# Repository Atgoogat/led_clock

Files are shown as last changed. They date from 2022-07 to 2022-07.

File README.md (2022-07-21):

# LED Clock

This is the pcb and software for a clock showing the time as three vertical led bars. 

The hours are split in two bars, 13h to 23h and 1h-12h, while minutes are split in three groups of 15, 5 and single minutes. Summed up you can read the time.

Time is kept with an RTC-DS3231.
Because the outputs of the arduino uno are not sufficient, shift registers are used to output the time.

Result:
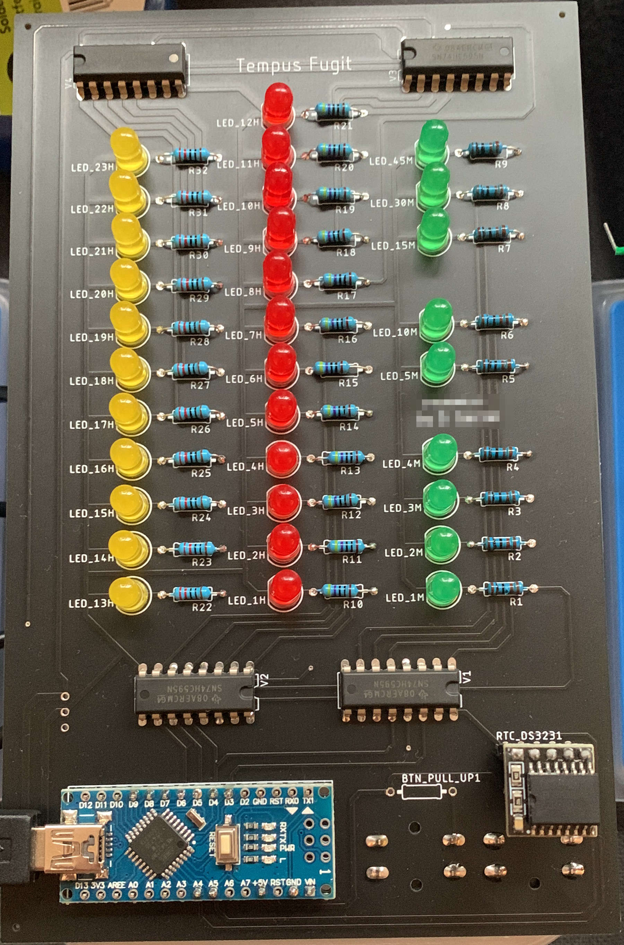
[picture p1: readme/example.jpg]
Result


## Questions

Please contact me via github if you have any questions or want to rebuild this clock 😉.

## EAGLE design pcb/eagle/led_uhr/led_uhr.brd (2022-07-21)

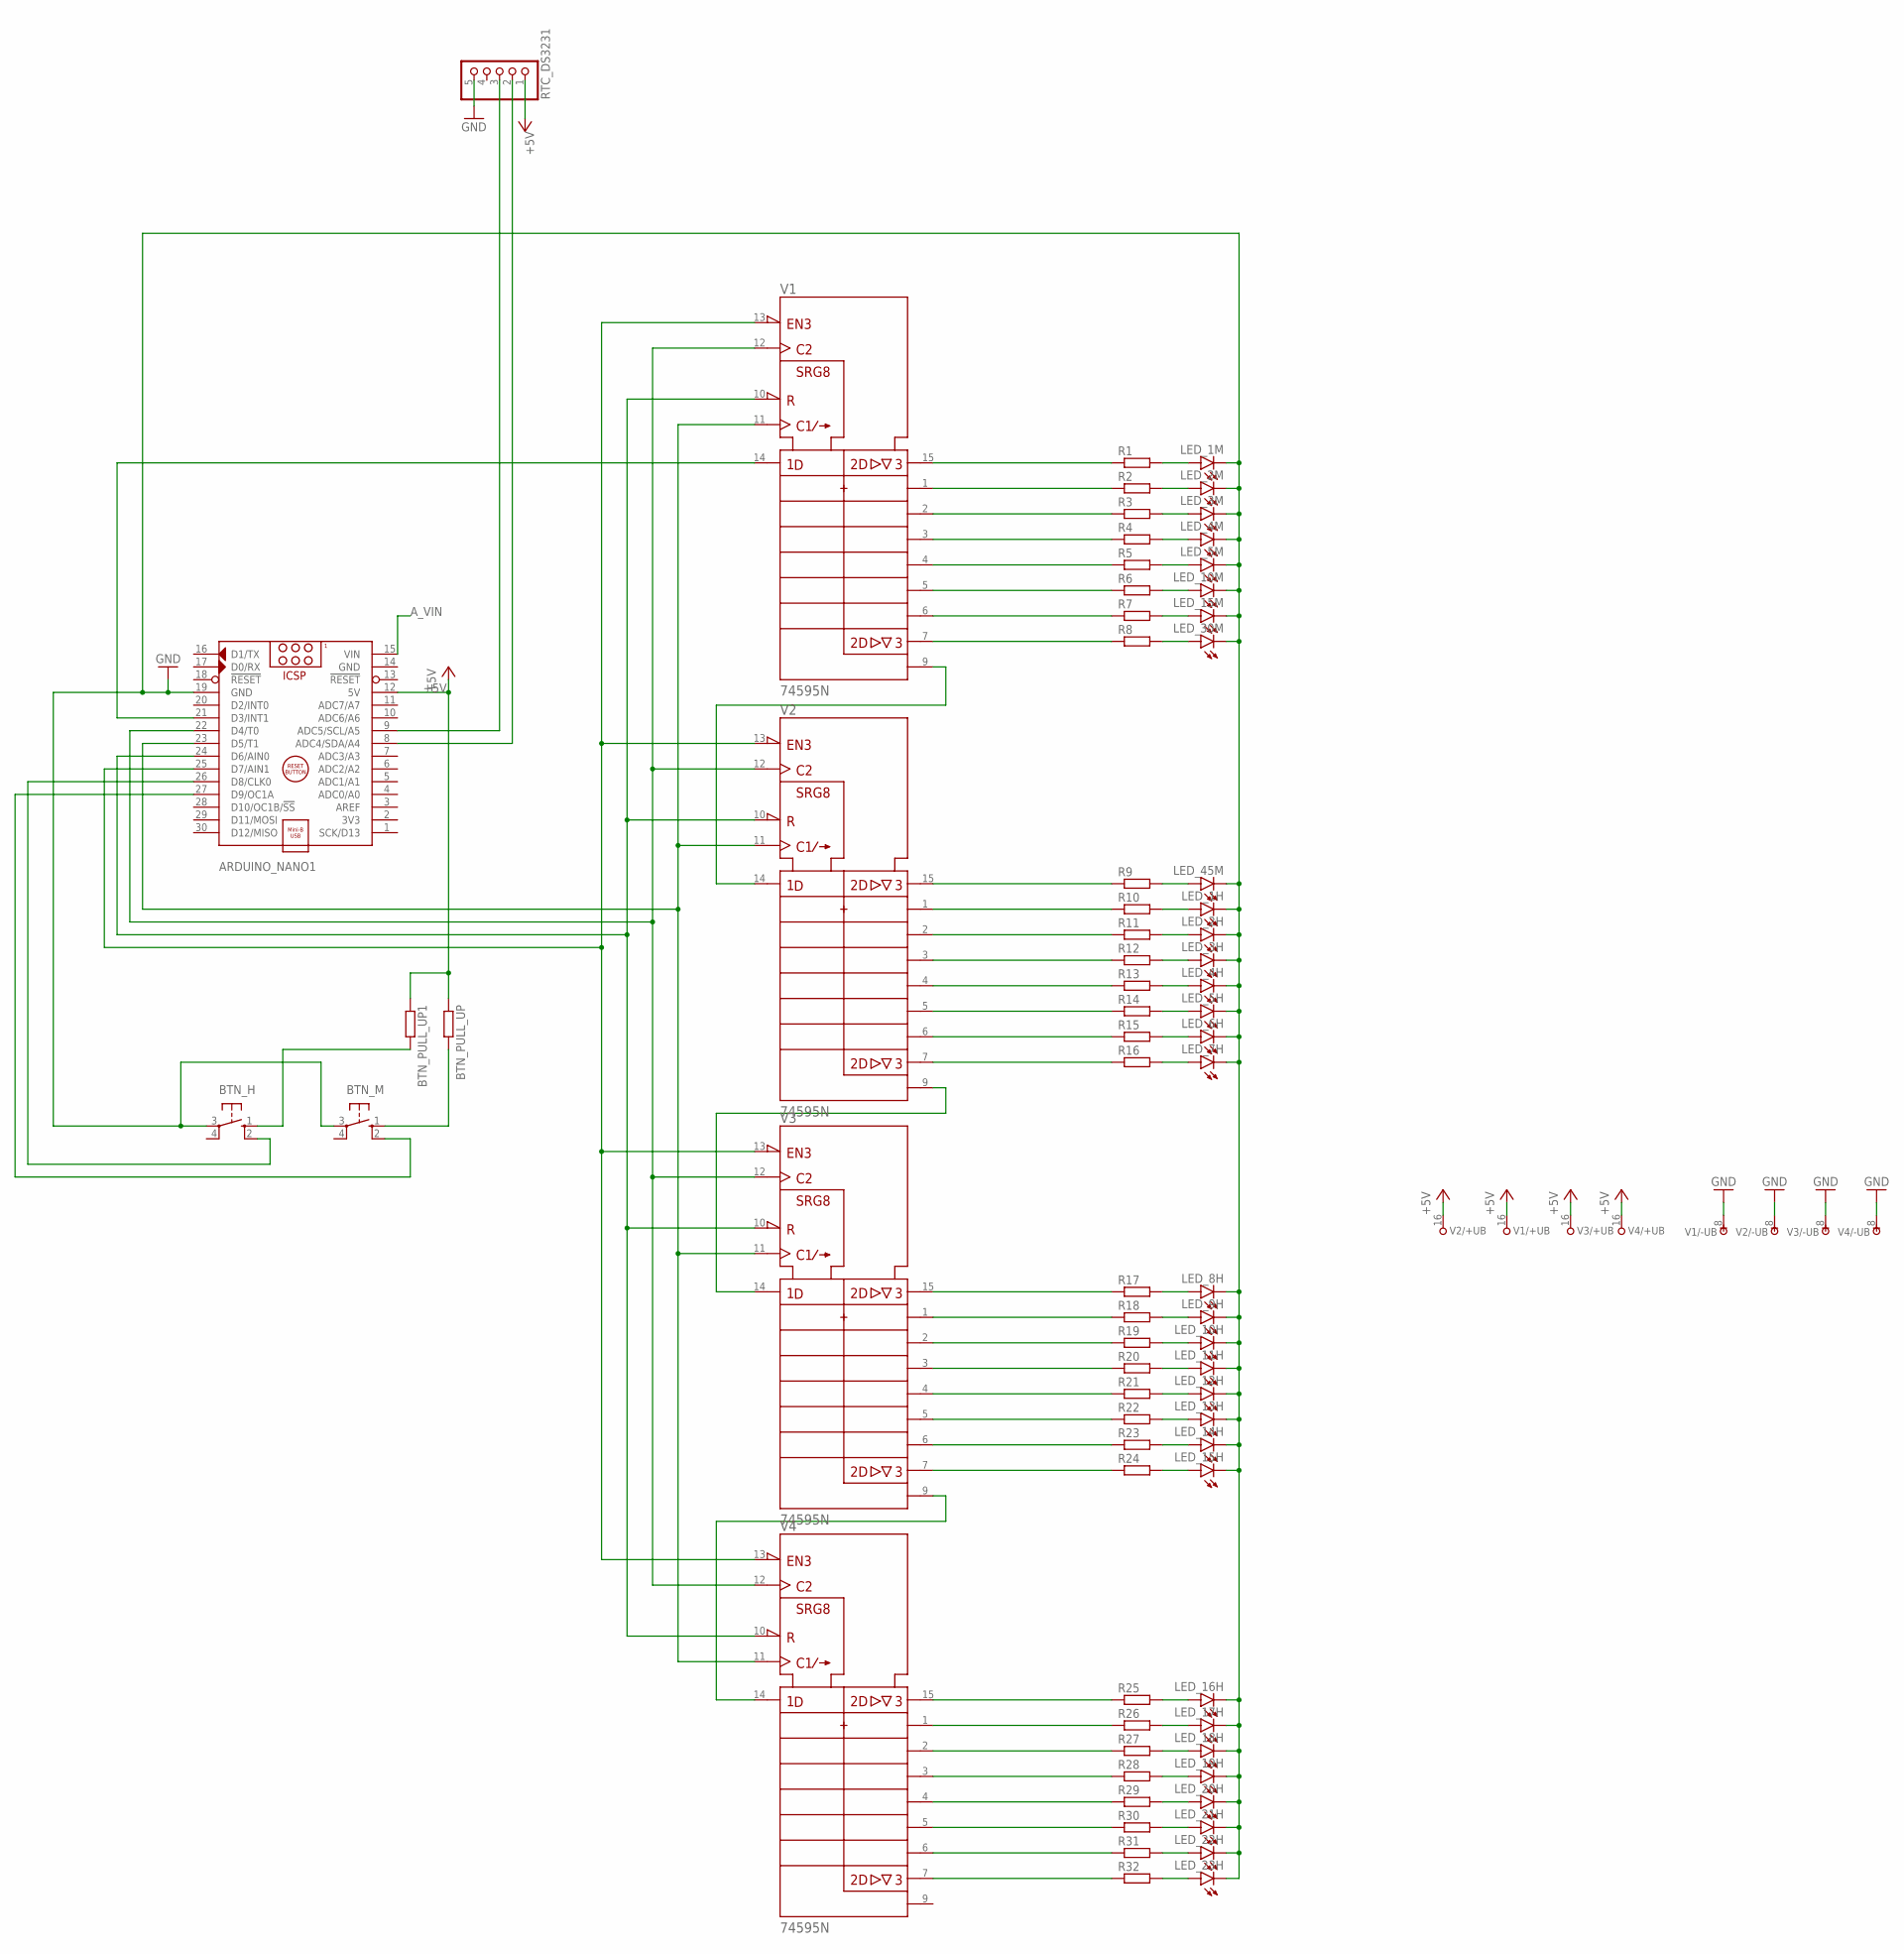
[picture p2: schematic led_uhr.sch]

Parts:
ARDUINO_NANO1: ARDUINO_NANO
BTN_H: 40-XX; B3F-40XX
BTN_M: 40-XX; B3F-40XX
BTN_PULL_UP, BTN_PULL_UP1: R-EU_0207/10; 0207/10
LED_1H, LED_1M, LED_2H, LED_2M, LED_3H, LED_3M, LED_4H, LED_4M, LED_5H, LED_5M, LED_6H, LED_7H, LED_8H, LED_9H, LED_10H, LED_10M, LED_11H, LED_12H, LED_13H, LED_14H, LED_15H, LED_15M, LED_16H, LED_17H, LED_18H, LED_19H, LED_20H, LED_21H, LED_22H, LED_23H, LED_30M, LED_45M: LED5MM
R1, R2, R3, R4, R5, R6, R7, R8, R9, R10, R11, R12, R13, R14, R15, R16, R17, R18, R19, R20, R21, R22, R23, R24, R25, R26, R27, R28, R29, R30, R31, R32: R-EU_0207/10; 0207/10
RTC_DS3231: PINHD-1X5; 1X05
V1, V2, V3, V4: 74595N; DIL16

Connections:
+5V: ARDUINO_NANO1.12 (5V), BTN_PULL_UP.1, BTN_PULL_UP1.1, RTC_DS3231.1, V1.16 (+UB), V2.16 (+UB), V3.16 (+UB), V4.16 (+UB)
A_VIN: ARDUINO_NANO1.15 (VIN)
GND: ARDUINO_NANO1.14 (GND), ARDUINO_NANO1.19 (GND), BTN_H.3, BTN_M.3, LED_1H.K (C), LED_1M.K (C), LED_2H.K (C), LED_2M.K (C), LED_3H.K (C), LED_3M.K (C), LED_4H.K (C), LED_4M.K (C), LED_5H.K (C), LED_5M.K (C), LED_6H.K (C), LED_7H.K (C), LED_8H.K (C), LED_9H.K (C), LED_10H.K (C), LED_10M.K (C), LED_11H.K (C), LED_12H.K (C), LED_13H.K (C), LED_14H.K (C), LED_15H.K (C), LED_15M.K (C), LED_16H.K (C), LED_17H.K (C), LED_18H.K (C), LED_19H.K (C), LED_20H.K (C), LED_21H.K (C), LED_22H.K (C), LED_23H.K (C), LED_30M.K (C), LED_45M.K (C), RTC_DS3231.5, V1.8 (-UB), V2.8 (-UB), V3.8 (-UB), V4.8 (-UB)
unnamed: R1.1, V1.15 (QA)
unnamed: R2.1, V1.1 (QB)
unnamed: R3.1, V1.2 (QC)
unnamed: R4.1, V1.3 (QD)
unnamed: R5.1, V1.4 (QE)
unnamed: R6.1, V1.5 (QF)
unnamed: R7.1, V1.6 (QG)
unnamed: R8.1, V1.7 (QH)
unnamed: R10.1, V2.1 (QB)
unnamed: R9.1, V2.15 (QA)
unnamed: R11.1, V2.2 (QC)
unnamed: R12.1, V2.3 (QD)
unnamed: R13.1, V2.4 (QE)
unnamed: R14.1, V2.5 (QF)
unnamed: R15.1, V2.6 (QG)
unnamed: R16.1, V2.7 (QH)
unnamed: R17.1, V3.15 (QA)
unnamed: R18.1, V3.1 (QB)
unnamed: R19.1, V3.2 (QC)
unnamed: R20.1, V3.3 (QD)
unnamed: R21.1, V3.4 (QE)
unnamed: R22.1, V3.5 (QF)
unnamed: R23.1, V3.6 (QG)
unnamed: R24.1, V3.7 (QH)
unnamed: R25.1, V4.15 (QA)
unnamed: R26.1, V4.1 (QB)
unnamed: R27.1, V4.2 (QC)
unnamed: R28.1, V4.3 (QD)
unnamed: R29.1, V4.4 (QE)
unnamed: R30.1, V4.5 (QF)
unnamed: R31.1, V4.6 (QG)
unnamed: R32.1, V4.7 (QH)
unnamed: V1.9 (QH*), V2.14 (SER)
unnamed: V2.9 (QH*), V3.14 (SER)
unnamed: V3.9 (QH*), V4.14 (SER)
unnamed: LED_1M.A, R1.2
unnamed: LED_2M.A, R2.2
unnamed: LED_3M.A, R3.2
unnamed: LED_4M.A, R4.2
unnamed: LED_5M.A, R5.2
unnamed: LED_10M.A, R6.2
unnamed: LED_15M.A, R7.2
unnamed: LED_30M.A, R8.2
unnamed: LED_45M.A, R9.2
unnamed: LED_1H.A, R10.2
unnamed: LED_2H.A, R11.2
unnamed: LED_3H.A, R12.2
unnamed: LED_4H.A, R13.2
unnamed: LED_5H.A, R14.2
unnamed: LED_6H.A, R15.2
unnamed: LED_7H.A, R16.2
unnamed: LED_8H.A, R17.2
unnamed: LED_9H.A, R18.2
unnamed: LED_10H.A, R19.2
unnamed: LED_11H.A, R20.2
unnamed: LED_12H.A, R21.2
unnamed: LED_13H.A, R22.2
unnamed: LED_14H.A, R23.2
unnamed: LED_15H.A, R24.2
unnamed: LED_16H.A, R25.2
unnamed: LED_17H.A, R26.2
unnamed: LED_18H.A, R27.2
unnamed: LED_19H.A, R28.2
unnamed: LED_20H.A, R29.2
unnamed: LED_21H.A, R30.2
unnamed: LED_22H.A, R31.2
unnamed: LED_23H.A, R32.2
unnamed: ARDUINO_NANO1.23 (D5/T1), V1.11 (SRCK), V2.11 (SRCK), V3.11 (SRCK), V4.11 (SRCK)
unnamed: ARDUINO_NANO1.24 (D6/AIN0), V1.10 (!SRCLR), V2.10 (!SRCLR), V3.10 (!SRCLR), V4.10 (!SRCLR)
unnamed: ARDUINO_NANO1.21 (D3/INT1), V1.14 (SER)
unnamed: ARDUINO_NANO1.22 (D4/T0), V1.12 (RCK), V2.12 (RCK), V3.12 (RCK), V4.12 (RCK)
unnamed: ARDUINO_NANO1.25 (D7/AIN1), V1.13 (!G), V2.13 (!G), V3.13 (!G), V4.13 (!G)
unnamed: BTN_M.1 (S), BTN_PULL_UP.2
unnamed: ARDUINO_NANO1.27 (D9/OC1A), BTN_M.2 (S1)
unnamed: ARDUINO_NANO1.9 (ADC5/SCL/A5), RTC_DS3231.3
unnamed: ARDUINO_NANO1.8 (ADC4/SDA/A4), RTC_DS3231.2
unnamed: ARDUINO_NANO1.26 (D8/CLK0), BTN_H.2 (S1)
unnamed: BTN_H.1 (S), BTN_PULL_UP1.2

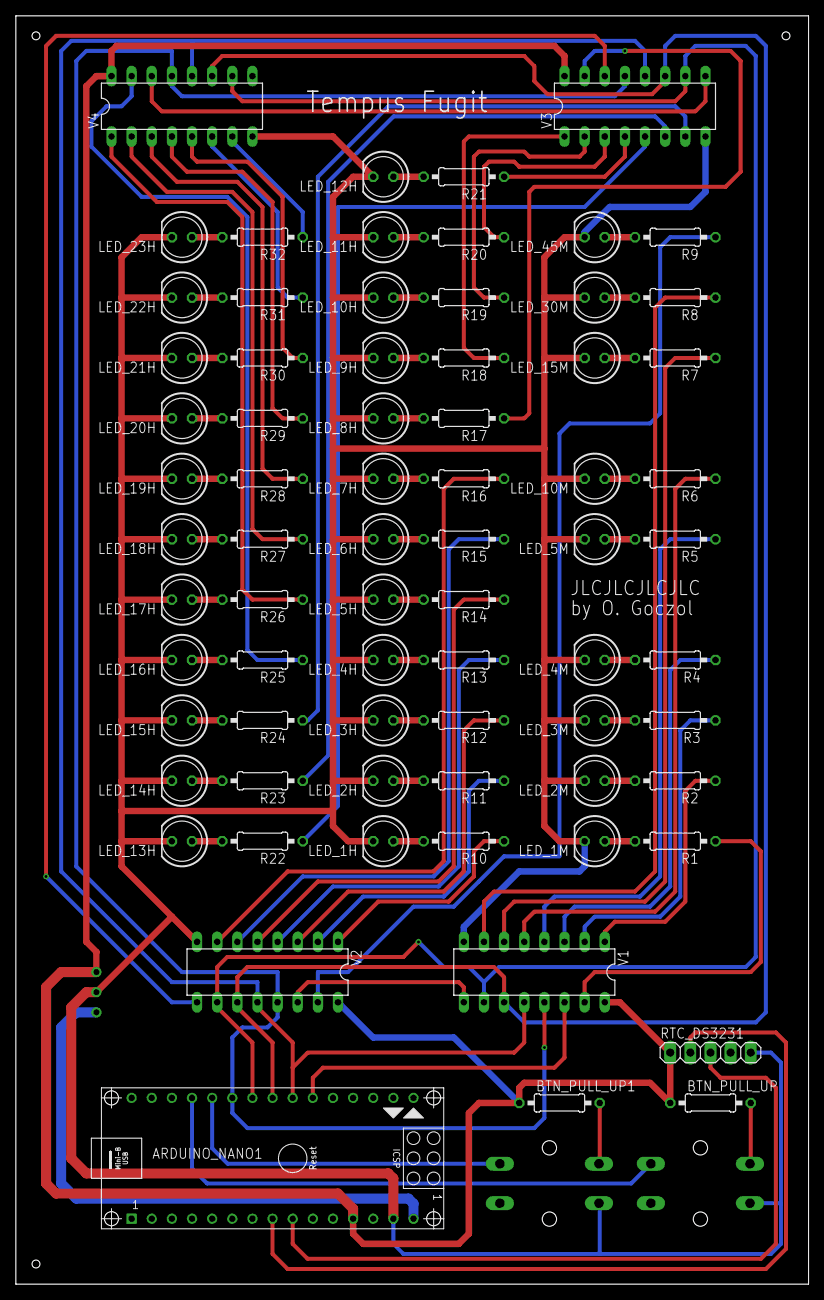
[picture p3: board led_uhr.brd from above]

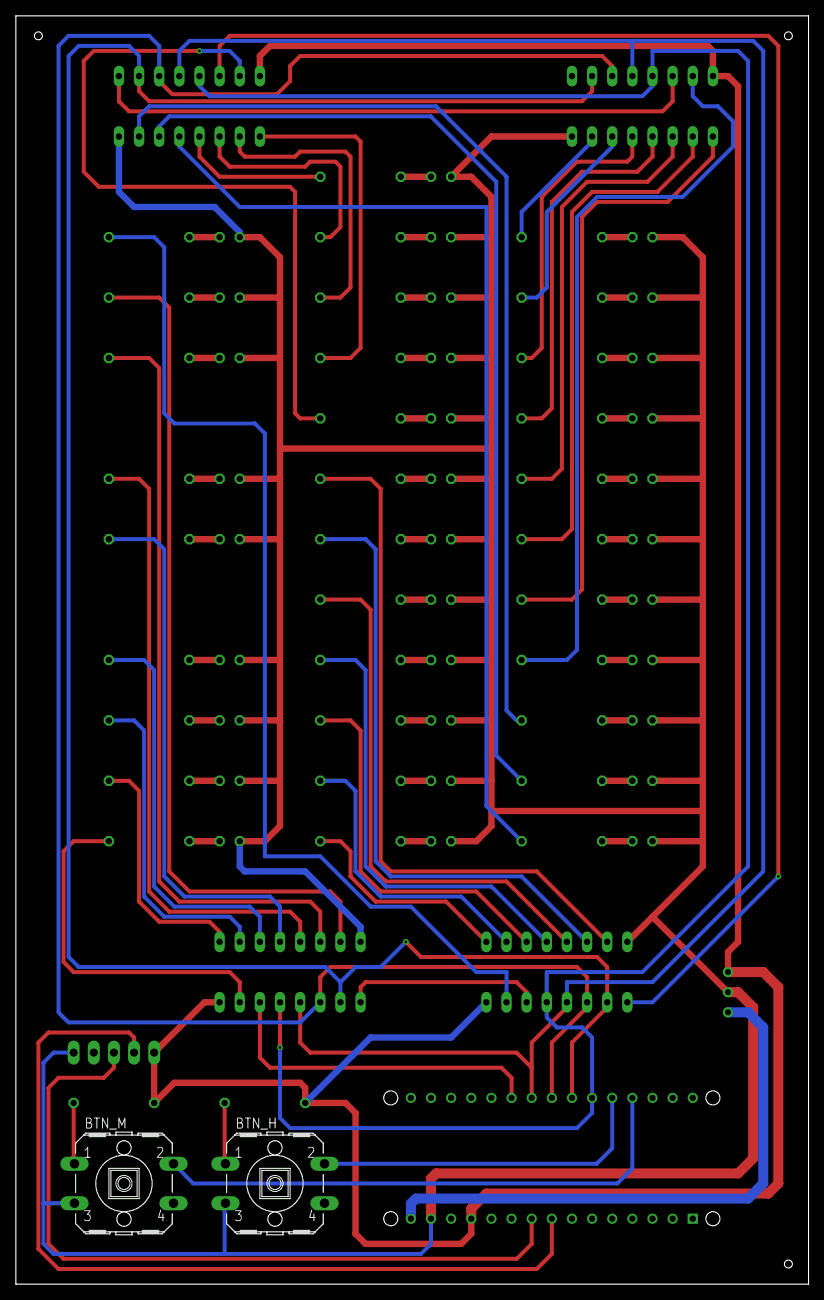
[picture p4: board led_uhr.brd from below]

Board: 2 copper layers, 100.0 x 160.0 mm, 74 parts (2 on the bottom side), 80 nets.

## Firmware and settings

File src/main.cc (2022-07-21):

#include <Arduino.h>
#include <RTClib.h>

#include "hang.h"
#include "led_clock.h"

#define SR_N_OE_PIN 7 // Output enabled (active low)
#define SR_N_MR_PIN 6 // Master Reset (active low)
#define SR_SHCP_PIN 5 // Shift Register Clock
#define SR_STCP_PIN 4 // Storage Register Clock 
#define SR_DS_PIN 3 // Data input

#define BTN_H_PIN 8
#define BTN_M_PIN 9

RTC_DS3231 rtc;

void setup() {
  pinMode(SR_N_OE_PIN, OUTPUT);
  digitalWrite(SR_N_OE_PIN, HIGH); // Disable all registers

  pinMode(SR_N_MR_PIN, OUTPUT);
  pinMode(SR_SHCP_PIN, OUTPUT);
  pinMode(SR_STCP_PIN, OUTPUT);
  pinMode(SR_DS_PIN, OUTPUT);

  pinMode(BTN_H_PIN, INPUT_PULLUP);
  pinMode(BTN_M_PIN, INPUT_PULLUP);

  // Reset all registers and active output
  digitalWrite(SR_N_MR_PIN, LOW);
  digitalWrite(SR_STCP_PIN, LOW);
  digitalWrite(SR_STCP_PIN, HIGH);
  digitalWrite(SR_N_MR_PIN, HIGH);
  digitalWrite(SR_N_OE_PIN, LOW);

  if (!rtc.begin()) {
    hang();
  }
  if (rtc.lostPower()) {
    const DateTime zero;
    rtc.adjust(zero);
  }
}

uint32_t last_mask = -1;
int last_btn_h_state = HIGH;
int last_btn_m_state = HIGH;
void loop() {

  const auto now = rtc.now();
  const SimpleTime time{
    now.minute(),
    now.hour()
  };

  const auto mask = cvtSimpleTime2Mask(time);
  
  if (mask != last_mask) {
    digitalWrite(SR_STCP_PIN, LOW);
    for(int i=0; i<32; ++i) {
      const auto output = mask & (uint32_t{1} << (31-i));
      const auto digitalOutput = output == 0 ? LOW : HIGH;

      digitalWrite(SR_SHCP_PIN, LOW);
      digitalWrite(SR_DS_PIN, digitalOutput);
      digitalWrite(SR_SHCP_PIN, HIGH);
    }
    digitalWrite(SR_STCP_PIN, HIGH);
    last_mask = mask;
  }

  const int btn_h_state = digitalRead(BTN_H_PIN);
  if (btn_h_state == LOW && last_btn_h_state == HIGH) {
    const uint8_t hour = (int16_t{now.hour()} + 1) % 24;
    const DateTime next{2000, 1, 1, hour, now.minute(), 0};
    rtc.adjust(next);
  }
  last_btn_h_state = btn_h_state;

  const int btn_m_state = digitalRead(BTN_M_PIN);
  if (btn_m_state == LOW && last_btn_m_state == HIGH) {
    const uint8_t min = (int16_t{now.minute()} + 1) % 60;
    const DateTime next{2000, 1, 1, now.hour(), min, 0};
    rtc.adjust(next);
  }
  last_btn_m_state = btn_m_state;

  delay(10);
}

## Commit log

2022-07-21 add: pcb files
    [led_uhr.brd, led_uhr.sch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]
2022-07-21 fix: set time modulo precedence
    [main.cc]
